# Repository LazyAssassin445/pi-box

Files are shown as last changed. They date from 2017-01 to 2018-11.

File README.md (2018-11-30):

piBox

# Raspberry Pi Birdbox
A wooden birdbox with some extra gadgets courtesy of the Raspberry Pi.

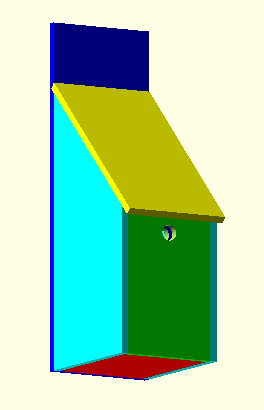
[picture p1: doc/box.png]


## Setting up the raspberry pi
Now you have your Raspberry Pi you need to put software on it. Go to this link https://www.raspberrypi.org/downloads/raspbian/ to download the latest copy of Raspbian
After it has downloaded, follow this link (https://www.raspberrypi.org/documentation/installation/installing-images/README.md) to learn how to install it onto your Pi
When you first boot up your pi it will come up with a login window, your login details are as follows
Username: pi
Password: raspberry
When you are in, type these commands into the PI's terminal window.

```console
pi@pibox:~ $ git clone https://github.com/LazyAssassin445/pi-box.git
pi@pibox:~ $ pip3 install smbus2
```

## Building
### Wood
#### Getting the Dimensions
Now you have cloned the repository onto your raspberry pi, do this:

```console
pi@pibox:~ $ cd pibox
pi@pibox:~/pibox $ python3 dimensions.py
```
You have to input the thickness of the wood and the amount of overhang you would like on the lid over the front. After that the program will print out the dimensions of the wood you need to cut and a diagram of how to cut the side panels.
You might have to scroll up to see all of the dimensions. Now cut the wood. 

#### Assembling the birdbox

You can install OpenSCAD (http://www.openscad.org/downloads.html) to look at the digital version of how the wood fits together.

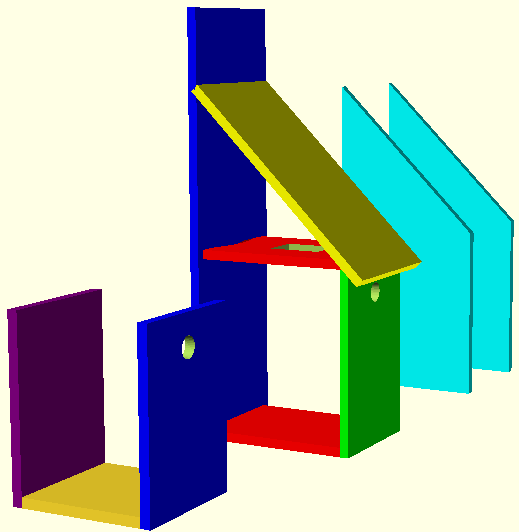
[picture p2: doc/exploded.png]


### Electronics
#### What You Need
#### Things that are shared between all of the boards
* Connector plugs
    - 5, 3 pin (http://bright-components.co.uk/epages/950004269.sf/en_GB/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)
    - 1, 4 pin (http://bright-components.co.uk/epages/950004269.sf/en_GB/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)
    - 1, 6 pin (http://bright-components.co.uk/epages/950004269.sf/en_GB/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)
    - 1, 2 pin (http://bright-components.co.uk/epages/950004269.sf/en_GB/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)
    - 1, 2 pin header (http://bright-components.co.uk)
* Wire

#### For the Ditribution Board You Need
* Strip Board (25 cols. x 20 rows)
* One Pi Cobbler (26 pins)
* If you have a newer Pi with 40 pins you will need a 40 pin to 26 pin ribbon cable
* If you have an older Pi with 26 pins you need a 26 pin ribbon cable

#### For the LED Boards You Need
* Strip Board
    -
* 6 850nm infared LED's
* 2 NPN Transistors
* 2 4.7k ohm resistors
* 2 1k ohm resistors

#### For the Force Sensing Board You Need
* Strip Board
    - 1 piece of 10 cols. x 13 rows 
    - 1 piece of 5 cols. x 5 rows
* Variable Resistor 100k (http://bright-components.co.uk/epages/950004269.sf/en_GB/?ObjectPath=/Shops/950004269/Products/3386_100K)
* Variable Resistor 10k (http://bright-components.co.uk/epages/950004269.sf/en_GB/?ObjectPath=/Shops/950004269/Products/3386_10K)
* A weight sensitive resistor (specifically https://goo.gl/8EGmAL)
* 1 16 pin IC socket
* 1 MCP 3008 ADC chip

#### For The POE Board You Need
* Strip board
* A buck converter
* A barrel connector
* A female USB type A socket

#### Assembling
#### Assembling the Distribution Board
First cut all of the nessesary tracks like so ...

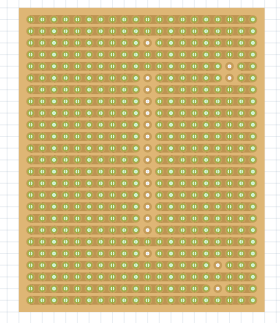
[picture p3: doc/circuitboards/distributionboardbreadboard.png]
distributionboardbreadboard


Then solder on the wires and the sockets (UART is the 3 pin header, not the plug), then the cobbler.

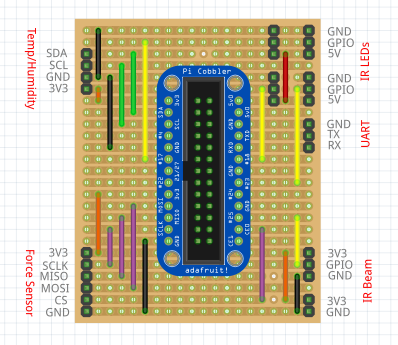
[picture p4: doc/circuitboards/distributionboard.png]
distributionboard


#### Assembling the Force Sensor Board
First cut all the tracks needed

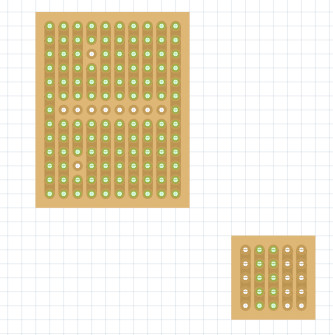
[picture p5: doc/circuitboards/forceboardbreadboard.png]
forceboardbreadboard


Then solder on the wires, the IC socket, the variable resistor and the plugs (2 pin)

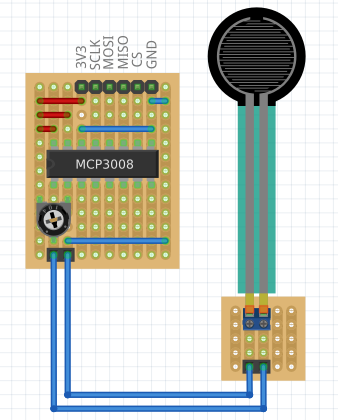
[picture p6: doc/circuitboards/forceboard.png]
forceboard


#### Assembling the LED Boards
First cut all the tracks needed

ledboardbreadboard

After that solder on the resistors, the connectors and the NPN transistor
### THEN SOLDER THE LEDS ON ON THE OTHER SIDE OF THE STRIP BOARD

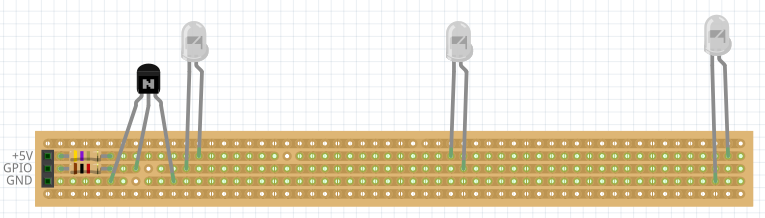
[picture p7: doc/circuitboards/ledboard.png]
ledboard


(not 100% accurate)

## Software
### Testing
Now that you have all of your things connected to your Pi (shown in the picture of the distribution board), we can get on with testing.

#### Force Sensor Testing
```console
pi@pibox:~ $ cd ~/pi-box/testprograms
pi@pibox:~/pi-box/testprograms $ python3 weighttest
```
#### Temperature/Humidity Sensor Testing
```console
pi@pibox:~ $ cd ~/pi-box/testprograms
pi@pibox:~/pi-box/testprograms $ python3 temphumidtest
```
#### LED Testing
Answer the question depending on where you have your LED boards plugged in
```console
pi@pibox:~ $ cd ~/pi-box/testprograms
pi@pibox:~/pi-box/testprograms $ python3 ledtest

What GPIO port would you like to test? 

```
#### Camera Testing
Answer the question depending on where you want to save the picture
```console
pi@pibox:~ $ cd ~/pi-box/testprograms/camera
pi@pibox:~/pi-box/testprograms/camera $ python3 oneshot

Where would you like to save this image? 

```

### Files you might want to look at
* https://cdn-learn.adafruit.com/downloads/pdf/adafruit-hdc1008-temperature-and-humidity-sensor-breakout.pdf
* https://cdn-shop.adafruit.com/datasheets/hdc1008.pdf

### Software you might want to download
* OpenSCAD (Used for the computer design of the birdbox) http://www.openscad.org/downloads.html
* Fritzing (Used for the computer design of the circuit boards) http://fritzing.org/download/

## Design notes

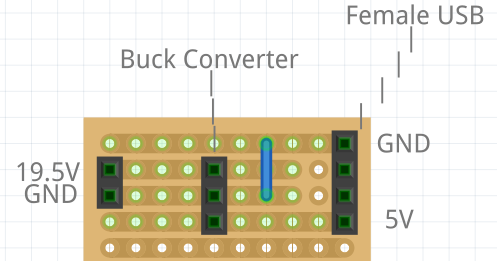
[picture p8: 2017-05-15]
doc/circuitboards/powerboard.png

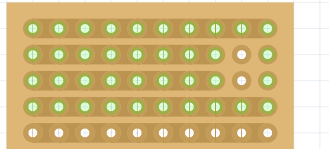
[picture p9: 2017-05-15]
doc/circuitboards/powerboardbreadboard.png

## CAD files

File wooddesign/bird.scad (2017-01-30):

//bottom plank (red)
color([1, 0, 0]) translate([12, 0, 0]) cube([194, 150, 12]);

//back plank (blue)
color([0, 0, 1]) translate([206, -12, 0]) cube([12, 174, 550]);

difference() {
	//front plank (green)
	color([0, 1, 0]) cube([12, 150, 234]);
	//hole
	translate([-10, 75, 196.5]) rotate(90, [0, 1, 0])
	    cylinder(44, 12.5, 12.5, false, $fa=1);
};

difference() {
    //top plank (red)
    color([1, 0, 0]) translate([0, 0, 234]) cube([206, 150, 12]);
    //window (perspex)
    translate([206/3, 150/3, 233]) cube([206/3, 50, 14]);
    //cable cut-out
    translate([347, 75, 233]) cylinder(44, 150, 150, center=true, $fa=1);
    
};

//top plank (yellow)
color([1,1,0]) translate([-25, -12, 225]) rotate(45, [0,1,0]) cube([12, 174, 325]);

//bird section
translate([0, 0, 0]) // UNEXPLODED
//translate([0, 400, 0]) // EXPLODED
{   
    //bottom plank (yellow)
    translate([34, 0, 22]) cube([150, 150, 12]);
    
    //back plank (green) 
    color("purple") translate([184, 0, 22]) cube([12, 150, 212]);
    
    difference() {
	//front plank (blue)
	color([0, 0, 1]) translate([22, 0, 22]) cube([12, 150, 212]);
	//hole
	translate([-10, 75, 196.5]) rotate(90, [0, 1, 0])
	    cylinder(49, 12.5, 12.5, false, $fa=1);
    };
};

//side planks (turquoise)
color([0, 1, 1])
translate([0, 0, 0]) // UNEXPLODED
//translate([0, -400, 0]) // EXPLODED
{
    //left side (from front)
    translate([0, 150, 0]) {
        //square section
        cube([206, 12, 234]);
        
        //triangle section
        translate([0, 12, 234])
        rotate(90, [1, 0, 0])
        linear_extrude(height = 12)
        polygon([[0, 0], [206, 0], [206, 206]]);
        
    }
    
    //right side (from front)
    translate([0, -12, 0]) {
        //square section
        cube([206, 12, 234]);
        
        //triangle section
        translate([0, 12, 234])
        rotate(90, [1, 0, 0])
        linear_extrude(height = 12)
        polygon([[0, 0], [206, 0], [206, 206]]);
    }
    
};

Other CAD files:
wooddesign/birddismantled.scad

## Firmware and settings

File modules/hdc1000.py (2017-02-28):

# Library for the temperature and humidity sensor
#  ----> https://www.adafruit.com/products/2635

import time
from pprint import pprint
import i2c

I2CADDR			= 0x40

TEMP_REG		= 0x00
HUMID_REG		= 0x01
CONFIG_REG		= 0x02

CONFIG_RESET		= (1 << 15)
CONFIG_HEAT		= (1 << 13)
CONFIG_MODE_SINGLE	= 0
CONFIG_MODE_BOTH	= (1 << 12)
CONFIG_BATT		= (1 << 11)
CONFIG_TRES_14		= 0
CONFIG_TRES_11		= (1 << 10)
CONFIG_HRES_14		= 0
CONFIG_HRES_11		= (1 << 8)
CONFIG_HRES_8		= (1 << 9)

SERIAL1			= 0xFB
SERIAL2			= 0xFC
SERIAL3			= 0xFD
MANUFID			= 0xFE
DEVICEID		= 0xFF

bus = i2c.IIC(I2CADDR, 1)

def reset(extra = 0):
	config = (
		CONFIG_RESET |
		CONFIG_MODE_SINGLE |
		CONFIG_TRES_14 |
		CONFIG_HRES_14 |
		extra
	)
	bus.i2c([CONFIG_REG, config >> 8, config & 0xff], 0)
	time.sleep(0.2)

def temperature():
	# Request temperature measurement
	bus.i2c([TEMP_REG], 0)

	time.sleep(0.2)

	data = bus.read(2)
	temp = (data[0] << 8) | data[1]
	#print(hex(temp))
	return (temp / 65536.0) * 165.0 - 40

def humidity():
	# Request humidity measurement
	bus.i2c([HUMID_REG], 0)

	time.sleep(0.2)

	data = bus.read(2)
	hum = (data[0] << 8) | data[1]
	#print(hex(hum))
	return (hum / 65536.0) * 100.0

def drySensor():
	# Turn on the heater
	reset(CONFIG_HEAT)

	# Take 1000 reading as fast as possible
	# (the heater is only activated when performing a reading)
	for x in range(1000):
		try:
			temperature()
		except: pass

	# Turn off the heater
	reset()

def init():
	reset()

def done():
	global bus
	bus.close()
	del bus

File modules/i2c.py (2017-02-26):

#!/usr/bin/env python

# Contributed by Raju and updated by Jim
# 
# Use:
# import i2c 
# device = i2c.IIC(<device i2c address 7 bit>,<Bus number>)
# example
# dev = i2c.IIC(0x32,1)
# dev.i2c([10,1,0,1],1) # sends bytes 10,1,0,1 and returns 1 byte
# dev.close()
#
import io
import fcntl

# i2c.py
# 2016-03-14
# Public Domain

I2C_SLAVE=0x0703

# Based on 'notSMB' for an easier way to access the i2c bus using just one
# function. The main difference between this and notSMB is that the bus
# here will be dedicated to 1 device address
class IIC:
   def __init__(self, device, bus):

      self.fr = io.open("/dev/i2c-"+str(bus), "rb", buffering=0)
      self.fw = io.open("/dev/i2c-"+str(bus), "wb", buffering=0)

      # set device address

      fcntl.ioctl(self.fr, I2C_SLAVE, device)
      fcntl.ioctl(self.fw, I2C_SLAVE, device)

   def write(self, data):
      if type(data) is list:
         data = bytes(data)
      self.fw.write(data)

   def read(self, count):
      s = ''
      l = []
      s = self.fr.read(count)
      return s
      #if len(s) != 0:
      #         for n in s:
      #            l.append(rd(n))
      #      return l
    

   def close(self):
      self.fw.close()
      self.fr.close()
      
   def i2c(self,listin,nout):
       self.write(bytearray(listin))
       rv = 0
       if nout != 0:
           rv = self.read(nout)
       return rv    

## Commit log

2017-01-29 Adding Base Files
    [bird.scad, birddismantled.scad]
2017-01-29 Changed back plank and side planks
    [bird.scad, birddismantled.scad]
2017-01-30 change hole from black cylinder to real hole
    [bird.scad, birddismantled.scad]
2017-01-30 Fixed multiple issues with the OpenSCAD files, modified README.scad
    [bird.scad, birddismantled.scad]
2017-01-30 Added window and cable cut out, wrote script to automatically change birddismantled.scad to explode it
    [bird.scad, birddismantled.scad]
2017-02-23 File organisation
    [LED.fzz, bird.scad, birddismantled.scad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]
2017-02-23 add Distribution_Board.fzz
    [Distribution_Board.fzz]
2017-02-23 arenaming files
    [distribution_board.fzz, led_board.fzz]
2017-02-25 alternate approach for reading data from sensor
2017-02-27 Add labels to connection points
    [distribution_board.fzz]
2017-02-28 Organisation and delete temphumidtest
    [distribution_board.fzz, force_sensor.fzz, led_board.fzz]
2017-02-28 Changed cuts
    [distribution_board.fzz]
2017-03-11 Updated fetchprogram, ignores pycache, created ledtest with npn
2017-03-11 Add ledtest program, update oneshot
2017-03-14 Finished LED test program (The extra setups at the top are needed to clear the gpio pin)
2017-03-14 Update LED board for new layout following testing
    [led_board.fzz]
2017-03-14 New Shell to controll GPIO PIN's
2017-03-19 Massive update to README and added pictures
    [distribution_board.fzz]
2017-05-15 Added Power board
    [power_board.fzz]
